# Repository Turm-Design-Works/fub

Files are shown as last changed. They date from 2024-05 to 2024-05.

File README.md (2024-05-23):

# fub.*~
**Pocket MIDI interface for Foot Switch &amp; Expression Pedal**  
  
Type-C :  
> to HOST

6.35 jack × 4 :  
> LEFT 2 jacks | Foot Switch jack. (Dual Foot Switch is available.)  
> RIGHT 2 jacks | Expression Pedal jack.

DIN 5pin × 1 :  
> MIDI OUT. This outputs MIDI datas of Foot SWs&Pedals and Note,CC,etc from Host.  

It is using ATSAND21G18A microcom chip as core.  



# LICENSES  
**MIT** ( [view LICENSE](https://github.com/Turm-Design-Works/fub/blob/main/LICENSE) )  
2024 Turm Design Works LLC.

# How to install firmware  
It needs to install "microchip(Atmel) studio", and prepare SAM/ARM writer (e. Atmel ICE, PICkit, j-link) with 5 debug wires.  
  
1. Solder all parts.
2. Connect fub.*~ & SAM/ARM writer to your PC.
3. Connect writer to fub.*~ PCB empty holes is marked "R V G C D" by using debug wire.  
> R: RESET, V: VTG 3.3V, G: GND, C: SWCLK, D: SWDIO  
> Please follow the connection of writer outputs you use.  
>   
4. Open microchip studio application.
> Move to "Tools" -> "Device Programming".  
>   
5. Apply writer and read chip.
> 1: Select writer you use, 2: Select Device "ATSAMD21G18A", 3: Select Interface "SWD",  
> 4: Click "Apply", 5: Click "Read"  
>   
6. Move to memories tab, program .hex firmware.
> 1: Click "Erase now", 2: Select fub_boot_v.v.v.v.hex firmware, 3: Click "Program"
>   
7. Disconnect fub.*~ and ARM writer from PC, and disconnect debug wire. Done.

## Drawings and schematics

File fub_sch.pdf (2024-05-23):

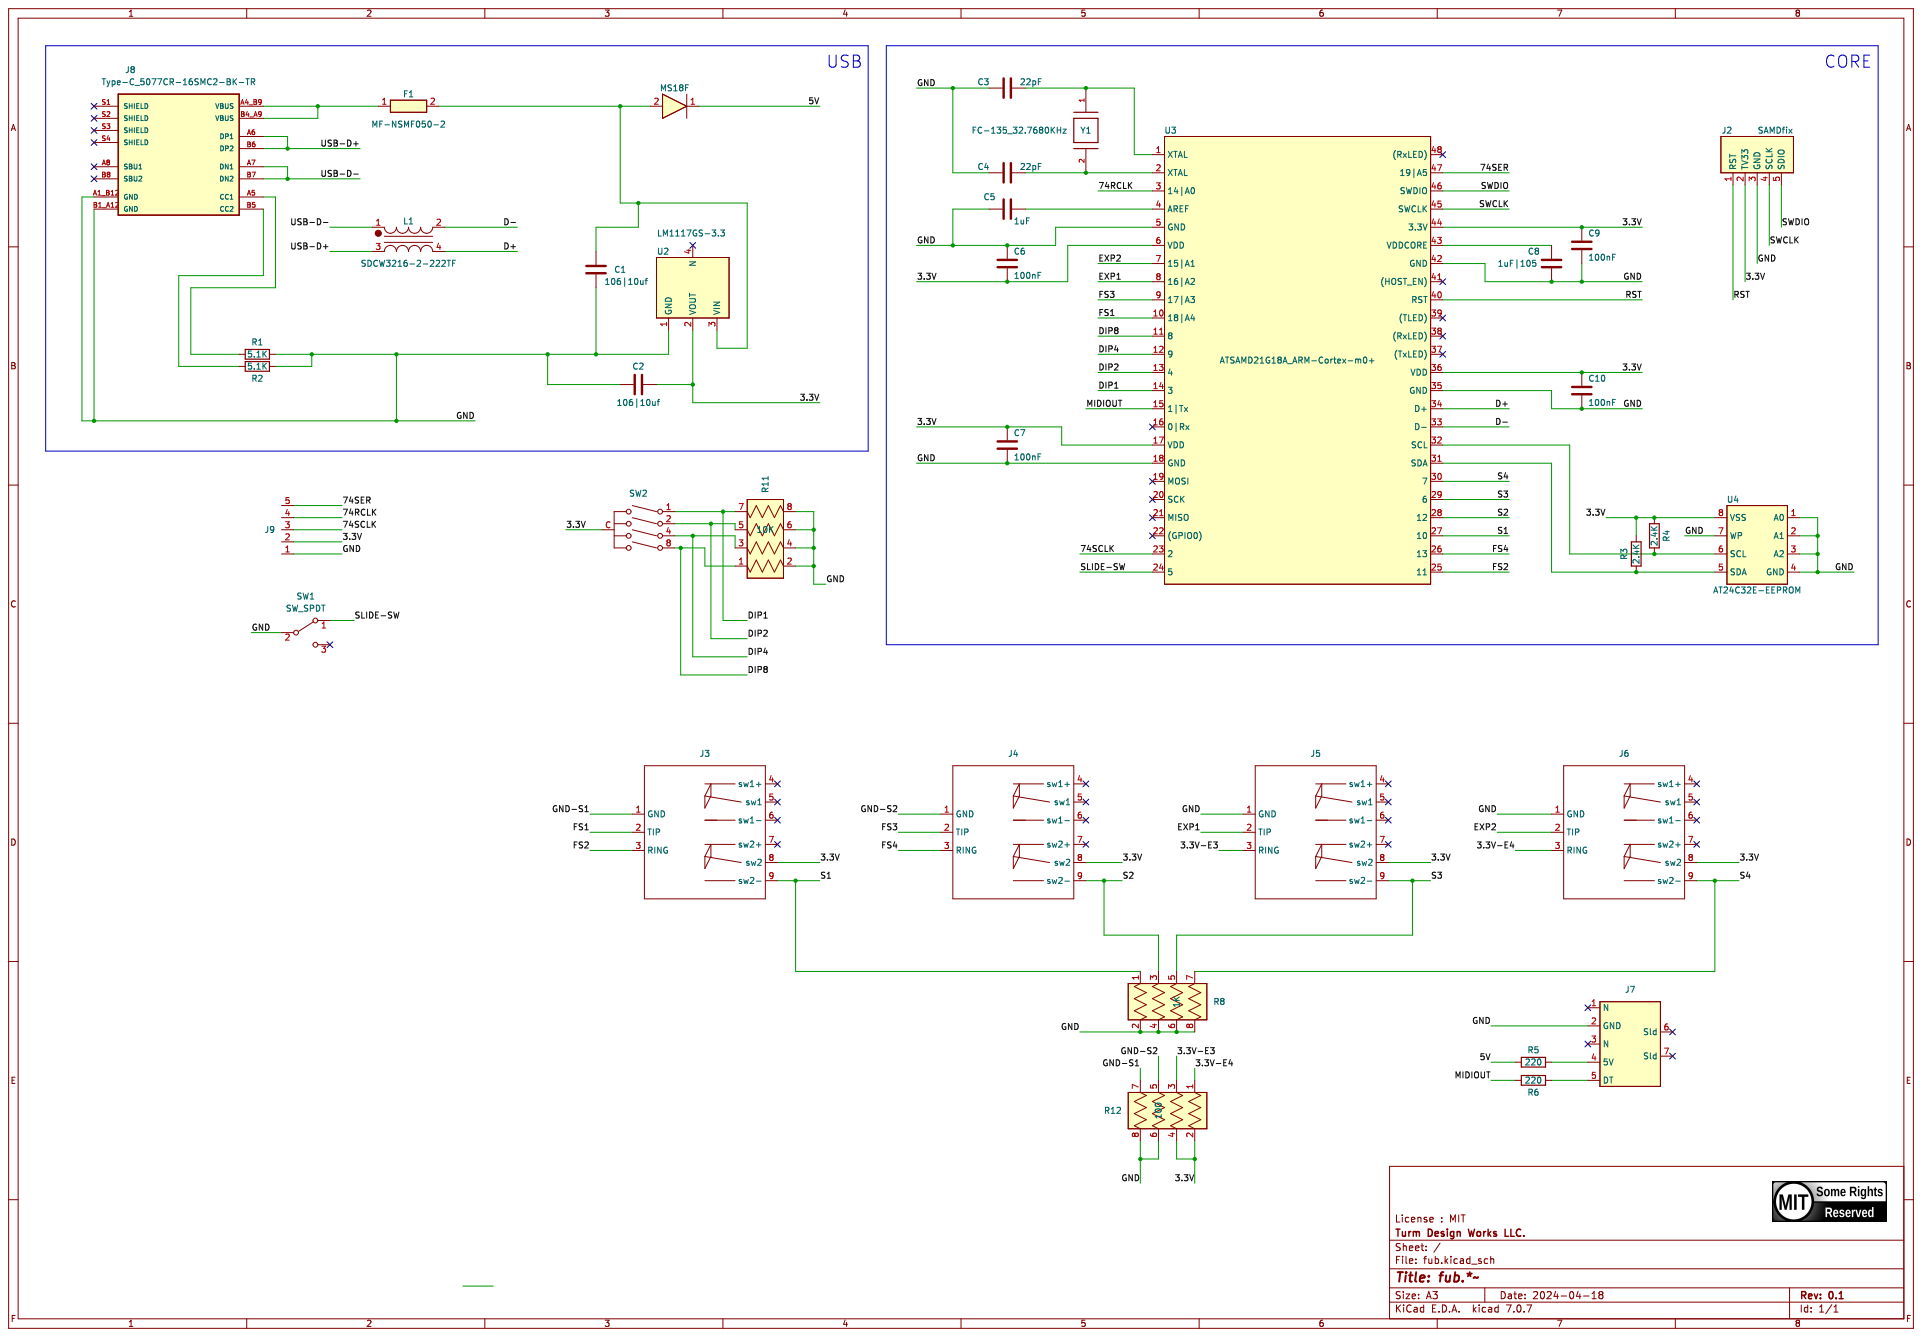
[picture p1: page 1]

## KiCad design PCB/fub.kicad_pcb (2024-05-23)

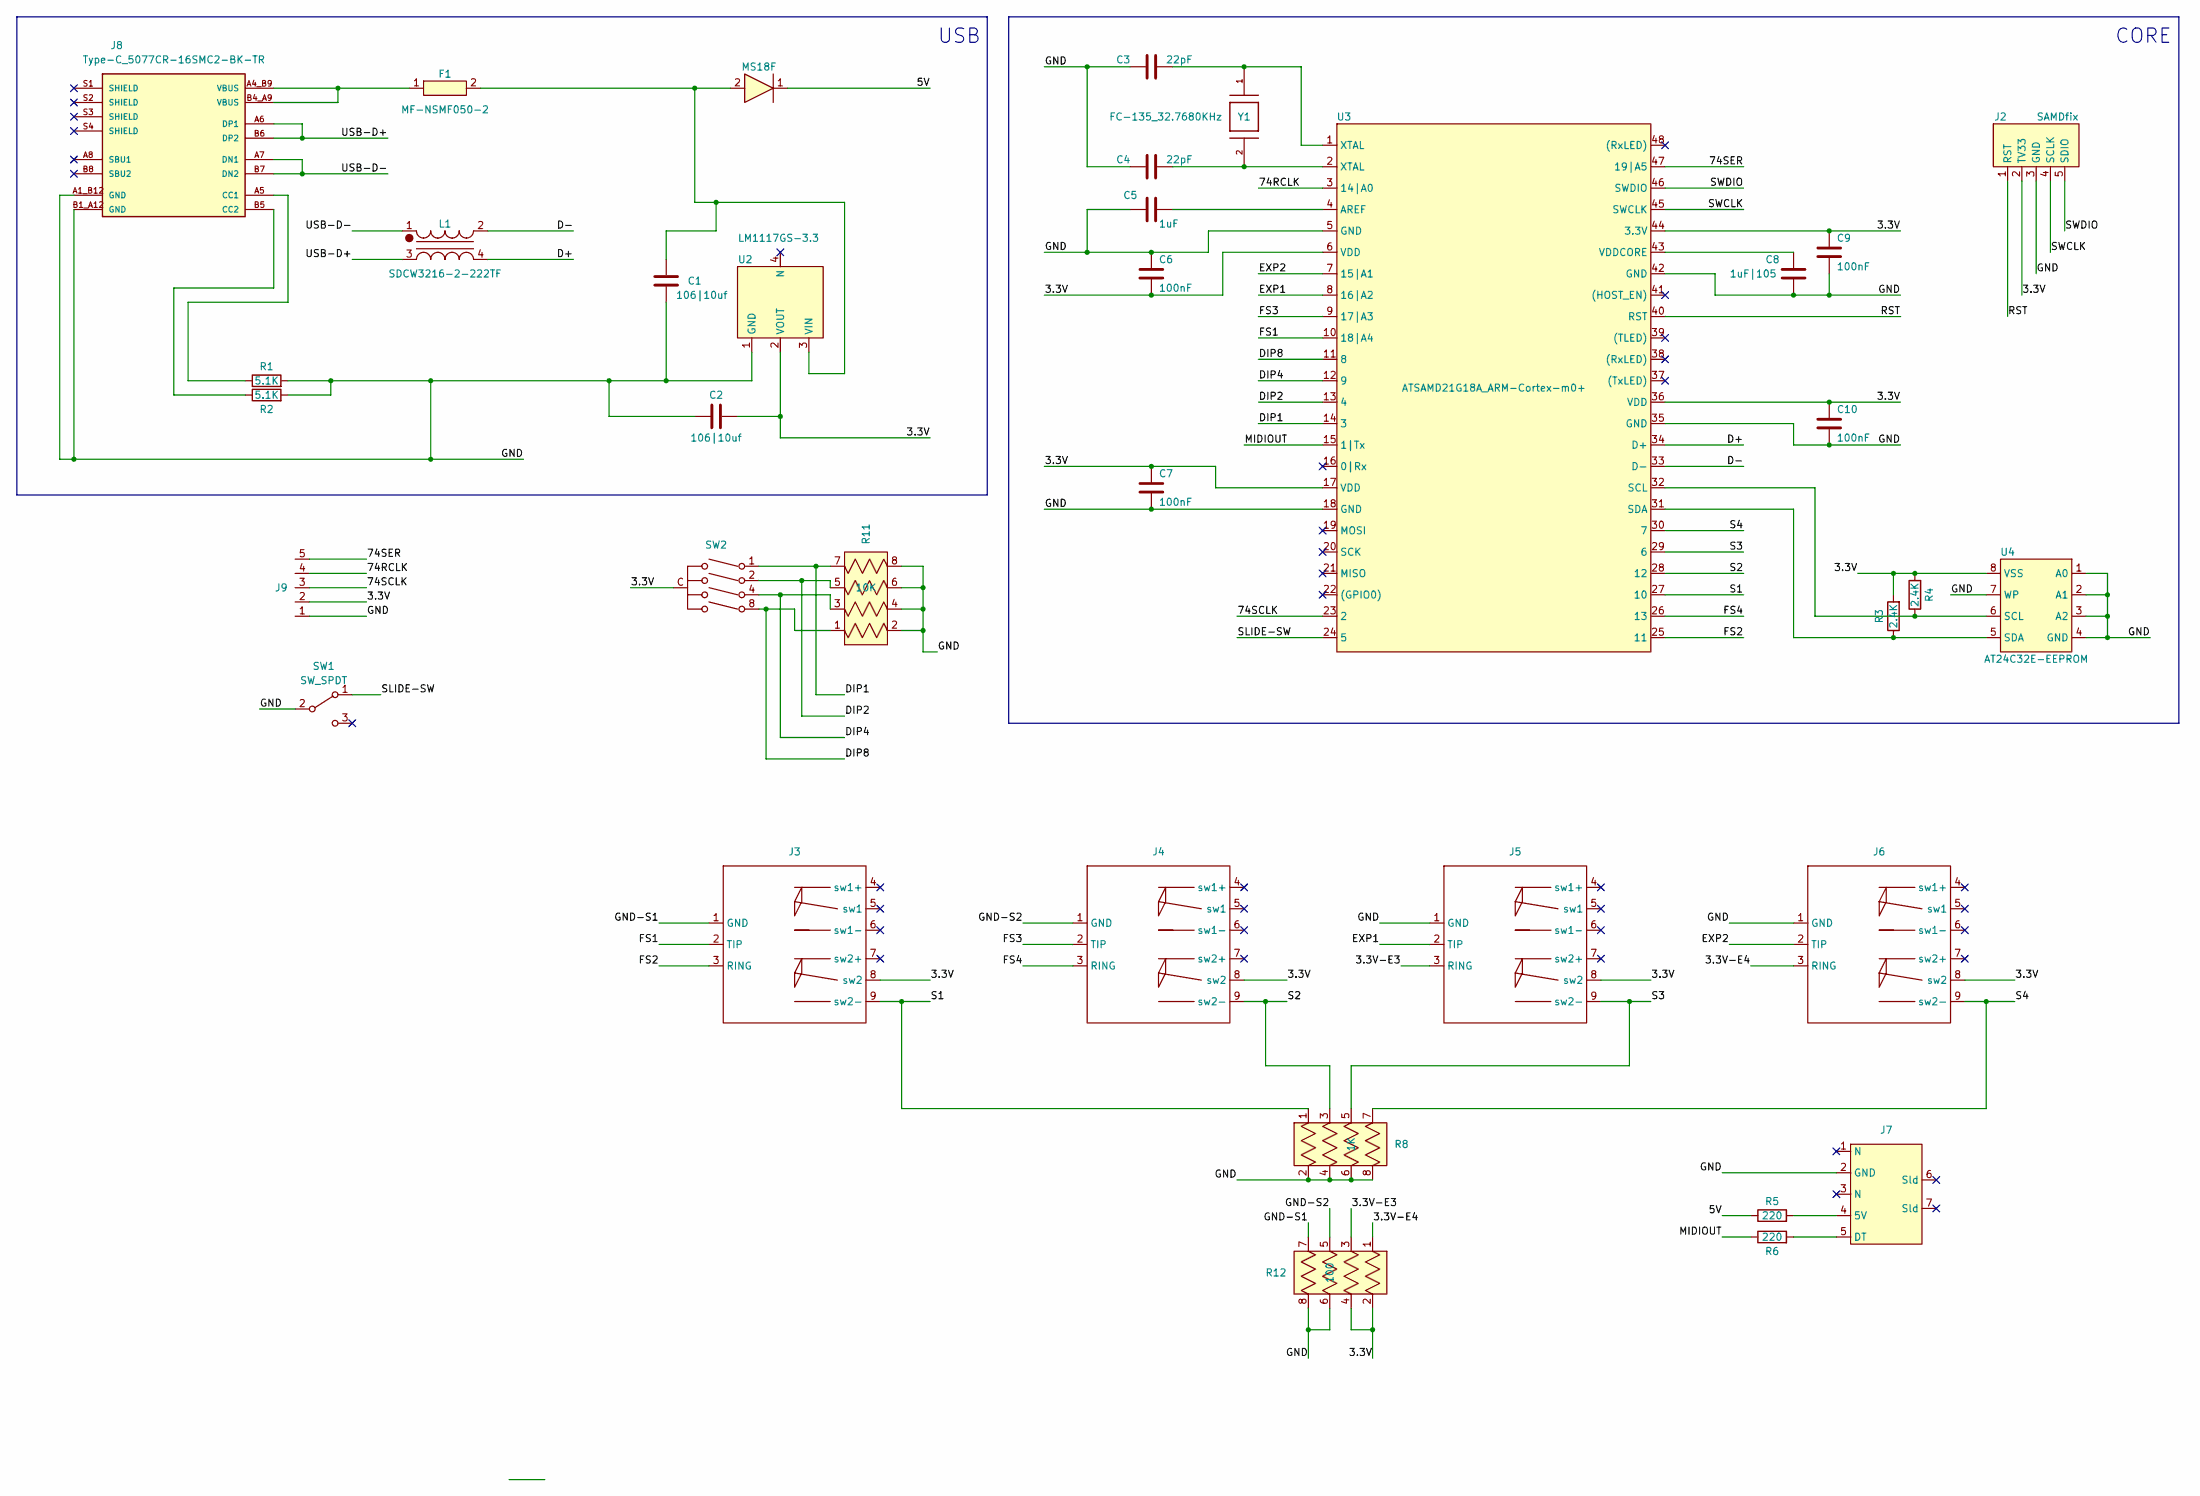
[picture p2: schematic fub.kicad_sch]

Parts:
C1, C2: 106|10uf; C_0603_1608Metric
C3, C4: 22pF; C_0603_1608Metric
C5: 1uF; C_0603_1608Metric
C6, C7, C9, C10: 100nF; C_0603_1608Metric
C8: 1uF|105; C_0603_1608Metric
F1: MF-NSMF050-2; MF-NSMF
J2: SAMDfix; 5tht
J3, J4, J5, J6: MJ-188LPD-8C
J7: KDJ03-5_MIDI
J8: Type-C_5077CR-16SMC2-BK-TR; NELTRON_5077CR-16SMC2-BK-TR
J9: 5ZH
L1: SDCW3216-2-222TF
R1, R2: 5.1K; R_0603_1608Metric
R3, R4: 2.4K; R_0603_1608Metric
R5, R6: 220; R_0603_1608Metric
R8: 1K; BCN164AB221J7
R11: 10K; MNR04M0ABJ103_register-arrray-small
R12: 100; BCN164AB221J7
SW1: SW_SPDT; SS-12D01G3_SLIDE-SW
SW2: FR01_dip-rotary16
U1: MS18F; MS18F_BARRIER
U2: LM1117GS-3.3; SOT-223
U3: ATSAMD21G18A_ARM-Cortex-m0+; QFP50P900X900X120-48N
U4: AT24C32E-EEPROM; SOIC-8_3.9x4.9mm_P1.27mm
Y1: FC-135_32.7680KHz; XTAL_FC-135_32.7680KA-A0

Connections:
/3.3V: C2.2, C6.1, C7.2, C9.2, C10.2, J2.2 (TV33), J3.8 (sw2), J4.8 (sw2), J5.8 (sw2), J6.8 (sw2), J9.2, R3.2, R4.2, R12.2, R12.4, SW2.C, U2.2 (VOUT), U3.6 (VDD), U3.17 (VDD), U3.36 (VDD), U3.44 (3.3V), U4.8 (VSS)
/3.3V-E3: J5.3 (RING), R12.3
/3.3V-E4: J6.3 (RING), R12.1
/5V: R5.1, U1.1
/74RCLK: J9.4, U3.3 (14|A0)
/74SCLK: J9.3, U3.23 (2)
/74SER: J9.5, U3.47 (19|A5)
/D+: L1.4, U3.34 (D+)
/D-: L1.2, U3.33 (D-)
/DIP1: R11.7, SW2.1, U3.14 (3)
/DIP2: R11.5, SW2.2, U3.13 (4)
/DIP4: R11.3, SW2.4, U3.12 (9)
/DIP8: R11.1, SW2.8, U3.11 (8)
/EXP1: J5.2 (TIP), U3.8 (16|A2)
/EXP2: J6.2 (TIP), U3.7 (15|A1)
/FS1: J3.2 (TIP), U3.10 (18|A4)
/FS2: J3.3 (RING), U3.25 (11)
/FS3: J4.2 (TIP), U3.9 (17|A3)
/FS4: J4.3 (RING), U3.26 (13)
/GND: C1.2, C2.1, C3.2, C4.2, C5.2, C6.2, C7.1, C8.1, C9.1, C10.1, J2.3 (GND), J5.1 (GND), J6.1 (GND), J7.2 (GND), J8.A1_B12 (GND), J8.B1_A12 (GND), J9.1, R1.2, R2.2, R8.2, R8.4, R8.6, R8.8, R11.2, R11.4, R11.6, R11.8, R12.6, R12.8, SW1.2 (B), U2.1 (GND), U3.5 (GND), U3.18 (GND), U3.35 (GND), U3.42 (GND), U4.1 (A0), U4.2 (A1), U4.3 (A2), U4.4 (GND), U4.7 (WP)
/GND-S1: J3.1 (GND), R12.7
/GND-S2: J4.1 (GND), R12.5
/MIDIOUT: R6.1, U3.15 (1|Tx)
/RST: J2.1 (RST), U3.40 (RST)
/S1: J3.9 (sw2-), R8.1, U3.27 (10)
/S2: J4.9 (sw2-), R8.3, U3.28 (12)
/S3: J5.9 (sw2-), R8.5, U3.29 (6)
/S4: J6.9 (sw2-), R8.7, U3.30 (7)
/SLIDE-SW: SW1.1 (A), U3.24 (5)
/SWCLK: J2.4 (SCLK), U3.45 (SWCLK)
/SWDIO: J2.5 (SDIO), U3.46 (SWDIO)
/USB-D+: J8.A6 (DP1), J8.B6 (DP2), L1.3
/USB-D-: J8.A7 (DN1), J8.B7 (DN2), L1.1
unnamed: C3.1, U3.1 (XTAL), Y1.1
unnamed: C4.1, U3.2 (XTAL), Y1.2
unnamed: F1.1, J8.A4_B9 (VBUS), J8.B4_A9 (VBUS)
unnamed: J7.4 (5V), R5.2
unnamed: J7.5 (DT), R6.2
unnamed: J8.A5 (CC1), R1.1
unnamed: J8.B5 (CC2), R2.1
unnamed: C1.1, F1.2, U1.2, U2.3 (VIN)
unnamed: C5.1, U3.4 (AREF)
unnamed: R4.1, U3.32 (SCL), U4.6 (SCL)
unnamed: R3.1, U3.31 (SDA), U4.5 (SDA)
unnamed: C8.2, U3.43 (VDDCORE)

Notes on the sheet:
CORE
USB

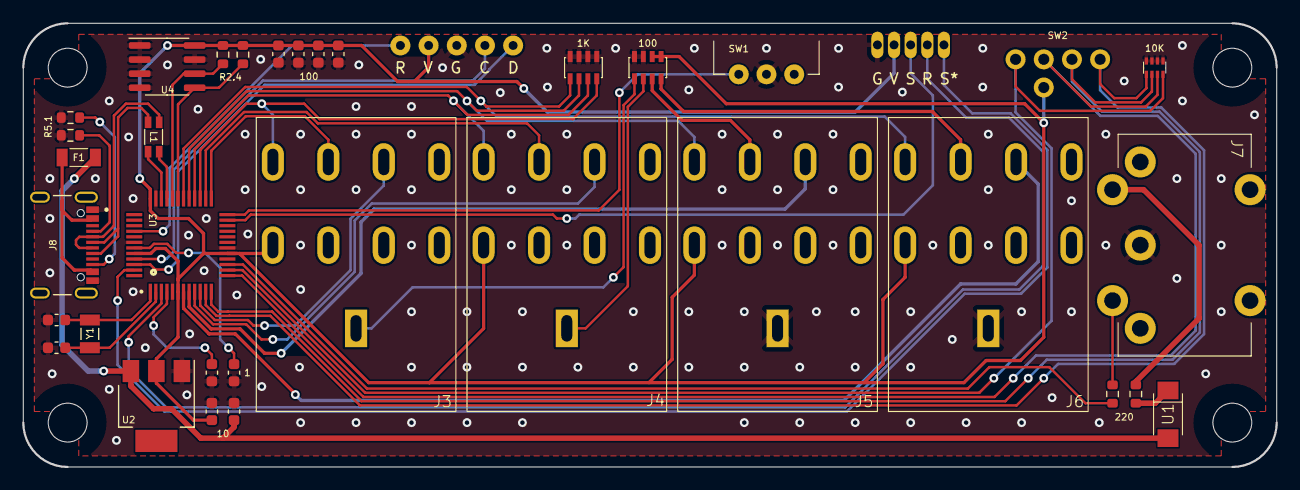
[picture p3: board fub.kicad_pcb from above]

Board: 2 copper layers, 113.0 x 40.0 mm, 36 parts (0 on the bottom side), 45 nets.

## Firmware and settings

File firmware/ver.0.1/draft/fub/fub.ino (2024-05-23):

/*
  SPDX-FileCopyrightText: 2024 Turm Design Works LLC. <info@turmdesignworks.com>
  SPDX-License-Identifier: MIT

  Seeed SAMD21 version 1.8.3 required.
*/

#include "MIDIUSB.h"
#include "Wire.h"

// average calc times
const byte AVGCT = 5;

// S Pins Switch
const int Pin_S[4] = {10, 12, 6, 7};

// V Pins Value (1-RING, 1-TIP, 2-RING, 2-TIP, 1-EXP, 2-EXP)
const int Pin_V[6] = {11, A4, 13, A3, A2, A1};

// Slide SW Pin
const int Pin_SL = 5;

// 7seg Pin
const int Pin_SER = A5;
const int Pin_SCLK = 2;
const int Pin_RCLK = A0;

// DIP Switch Pin
const int Pin_D[4] = {3, 4, 9, 8};

// DIP Switch Values
byte DIPV[4] = {0, 0, 0, 0};

// DIP Switch result
byte DIPNUM = 0;
byte DIPNUMp = 0;

// FS Random Value
byte RAND[4] = {0, 0, 0, 0};

/////////////////////////////////////////////// Function Mode
/////////////////////////////////////////////// FS : 0.Latch CC, 1.Moment CC, 2.Random CC, 3.PGM, 4.Note, 5.BANK++, 6.BANK--
/////////////////////////////////////////////// EXP: 0.CC, 1.CC (Reverse)
byte MODE[6] = {4, 4, 5, 6, 0, 0};

// BANK Value
byte BANK = 0;
byte BANKp = 255;

/////////////////////////////////////////////// FS+EXP MIDI Channel
byte MIDICH[6] = {0, 0, 0, 0, 0, 0};

/////////////////////////////////////////////// FS+EXP CCID
byte CCID[6] = {64, 65, 66, 67, 7, 11};

/////////////////////////////////////////////// EXP Curve
byte curve[2] = {1, 1};

/////////////////////////////////////////////// FS+EXP CC Minimum Value
byte MINV[6] = {0, 0, 0, 0, 0, 0};
/////////////////////////////////////////////// FS+EXP CC Maximum Value
byte MAXV[6] = {127, 127, 127, 127, 127, 127};

/////////////////////////////////////////////// FS CC Random Minimum Value
byte MINR[4] = {0, 0, 0, 0};
/////////////////////////////////////////////// FS CC Random Maximum Value
byte MAXR[4] = {127, 127, 127, 127};

/////////////////////////////////////////////// FS Program Change Value 0~127 outputs 1~128
byte PGMV[4] = {19, 20, 21, 22};

/////////////////////////////////////////////// FS Note Number
byte NOTE[4] = {48, 50, 52, 53};

/////////////////////////////////////////////// FS Velocity
byte VELO[4] = {64, 64, 64, 64};

/////////////////////////////////////////////// FS POLALITY TYPE
byte NCO[4] = {0, 0, 1, 1};

/////////////////////////////////////////////// EEPROM DATA to BANK
/////////////////////////////////////////////// 0~5:MODE, 6~11:MIDICH, 12~17:CCID, 18~19:Curve, 20~25:MINV, 26~31:MAXV,
/////////////////////////////////////////////// 32~35:MINR, 36~39:MAXR, 40~43:PGMV, 44~47:NOTE, 48~51:VELO, 52~55:NCO
byte EEPV[10][56] = { 
    { /*MODE*/ 1, 1, 6, 5, 0, 0, /*MIDICH*/ 0, 0, 0, 0, 0, 0, /*CCID*/ 64, 69, 0, 0, 7, 11, /*Curve*/ 1, 1, /*MINV*/ 0, 0, 0, 0, 0, 0, /*MAXV*/ 127, 127, 127, 127, 127, 127, /*MINR*/ 0, 0, 0, 0,  /*MAXR*/ 127, 127, 127, 127, /*PGMV*/ 0, 0, 0, 0, /*NOTE*/ 48, 50, 52, 53, /*VELO*/ 64, 64, 64, 64, /*NCO*/ 0, 0, 0, 0 },
    { /*MODE*/ 0, 0, 6, 5, 0, 0, /*MIDICH*/ 0, 0, 0, 0, 0, 0, /*CCID*/ 82, 83, 0, 0, 7, 11, /*Curve*/ 1, 1, /*MINV*/ 0, 0, 0, 0, 0, 0, /*MAXV*/ 127, 127, 127, 127, 127, 127, /*MINR*/ 0, 0, 0, 0,  /*MAXR*/ 127, 127, 127, 127, /*PGMV*/ 0, 0, 0, 0, /*NOTE*/ 48, 50, 52, 53, /*VELO*/ 64, 64, 64, 64, /*NCO*/ 0, 0, 0, 0 },
    { /*MODE*/ 2, 2, 6, 5, 0, 0, /*MIDICH*/ 0, 0, 0, 0, 0, 0, /*CCID*/ 1, 2, 0, 0, 7, 11, /*Curve*/ 1, 1, /*MINV*/ 0, 0, 0, 0, 0, 0, /*MAXV*/ 127, 127, 127, 127, 127, 127, /*MINR*/ 0, 0, 0, 0,  /*MAXR*/ 127, 127, 127, 127, /*PGMV*/ 0, 0, 0, 0, /*NOTE*/ 48, 50, 52, 53, /*VELO*/ 64, 64, 64, 64, /*NCO*/ 0, 0, 0, 0 },
    { /*MODE*/ 3, 3, 6, 5, 0, 0, /*MIDICH*/ 0, 0, 0, 0, 0, 0, /*CCID*/ 0, 0, 0, 0, 7, 11, /*Curve*/ 1, 1, /*MINV*/ 0, 0, 0, 0, 0, 0, /*MAXV*/ 127, 127, 127, 127, 127, 127, /*MINR*/ 0, 0, 0, 0,  /*MAXR*/ 127, 127, 127, 127, /*PGMV*/ 1, 2, 0, 0, /*NOTE*/ 48, 50, 52, 53, /*VELO*/ 64, 64, 64, 64, /*NCO*/ 0, 0, 0, 0 },
    { /*MODE*/ 4, 4, 6, 5, 0, 0, /*MIDICH*/ 0, 0, 0, 0, 0, 0, /*CCID*/ 0, 0, 0, 0, 7, 11, /*Curve*/ 1, 1, /*MINV*/ 0, 0, 0, 0, 0, 0, /*MAXV*/ 127, 127, 127, 127, 127, 127, /*MINR*/ 0, 0, 0, 0, /*MAXR*/ 127, 127, 127, 127, /*PGMV*/ 0, 0, 0, 0, /*NOTE*/ 48, 50, 52, 53, /*VELO*/ 64, 64, 64, 64, /*NCO*/ 0, 0, 0, 0 },
    { /*MODE*/ 1, 1, 6, 5, 1, 1, /*MIDICH*/ 0, 0, 0, 0, 0, 0, /*CCID*/ 64, 69, 0, 0, 7, 11, /*Curve*/ 1, 1, /*MINV*/ 0, 0, 0, 0, 0, 0, /*MAXV*/ 127, 127, 127, 127, 127, 127, /*MINR*/ 0, 0, 0, 0, /*MAXR*/ 127, 127, 127, 127, /*PGMV*/ 0, 0, 0, 0, /*NOTE*/ 48, 50, 52, 53, /*VELO*/ 64, 64, 64, 64, /*NCO*/ 0, 0, 0, 0 },
    { /*MODE*/ 0, 0, 6, 5, 1, 1, /*MIDICH*/ 0, 0, 0, 0, 0, 0, /*CCID*/ 82, 83, 0, 0, 7, 11, /*Curve*/ 1, 1, /*MINV*/ 0, 0, 0, 0, 0, 0, /*MAXV*/ 127, 127, 127, 127, 127, 127, /*MINR*/ 0, 0, 0, 0, /*MAXR*/ 127, 127, 127, 127, /*PGMV*/ 0, 0, 0, 0, /*NOTE*/ 48, 50, 52, 53, /*VELO*/ 64, 64, 64, 64, /*NCO*/ 0, 0, 0, 0 },
    { /*MODE*/ 2, 2, 6, 5, 1, 1, /*MIDICH*/ 0, 0, 0, 0, 0, 0, /*CCID*/ 1, 2, 0, 0, 7, 11, /*Curve*/ 1, 1, /*MINV*/ 0, 0, 0, 0, 0, 0, /*MAXV*/ 127, 127, 127, 127, 127, 127, /*MINR*/ 0, 0, 0, 0, /*MAXR*/ 127, 127, 127, 127, /*PGMV*/ 0, 0, 0, 0, /*NOTE*/ 48, 50, 52, 53, /*VELO*/ 64, 64, 64, 64, /*NCO*/ 0, 0, 0, 0 },
    { /*MODE*/ 3, 3, 6, 5, 1, 1, /*MIDICH*/ 0, 0, 0, 0, 0, 0, /*CCID*/ 0, 0, 0, 0, 7, 11, /*Curve*/ 1, 1, /*MINV*/ 0, 0, 0, 0, 0, 0, /*MAXV*/ 127, 127, 127, 127, 127, 127, /*MINR*/ 0, 0, 0, 0, /*MAXR*/ 127, 127, 127, 127, /*PGMV*/ 1, 2, 0, 0, /*NOTE*/ 48, 50, 52, 53, /*VELO*/ 64, 64, 64, 64, /*NCO*/ 0, 0, 0, 0 },
    { /*MODE*/ 4, 4, 6, 5, 1, 1, /*MIDICH*/ 0, 0, 0, 0, 0, 0, /*CCID*/ 0, 0, 0, 0, 7, 11, /*Curve*/ 1, 1, /*MINV*/ 0, 0, 0, 0, 0, 0, /*MAXV*/ 127, 127, 127, 127, 127, 127, /*MINR*/ 0, 0, 0, 0, /*MAXR*/ 127, 127, 127, 127, /*PGMV*/ 0, 0, 0, 0, /*NOTE*/ 48, 50, 52, 53, /*VELO*/ 64, 64, 64, 64, /*NCO*/ 0, 0, 0, 0 },
  };

// Jack Switch Values
byte ON[4] = {0, 0, 0, 0};
byte ONp[4] = {0, 0, 0, 0};

//EXP FLAG
byte outFLAG[2] = {0, 0};
byte outFLAGp[2] = {0, 0};

// Read Value is "times of for()"
int VAL[6] = {0, 0, 0, 0, 0, 0};
int VALp[6] = {0, 0, 0, 0, 0, 0};

// Foot Switch State for output pipe*~ delay
byte FS_State[4] = {0, 0, 0, 0};
byte FSp_State[4] = {0, 0, 0, 0};

// FootSwitch result Value
byte FootSwitch[4] = {0, 0, 0, 0};

// EXP Average of Vals
int AVV[2] = {0, 0};
int AVVp[2] = {0, 0};

//detect maxexpvalue
int MAXSTOMP[2] = {1011, 1011};

//detect minexpvalue
int MINSTOMP[2] = {24, 24};

//EXP sorted
byte EXP[2] = {0, 0};
byte EXPp[2] = {0, 0};

//EXP result
int EXPCCV[2] = {0, 0};
int EXPCCVp[2] = {0, 0};

//for output waiting time
unsigned long CTM[4] = {0, 0, 0, 0};

//for calc waiting time
unsigned long VTM[6] = {0, 0, 0, 0, 0, 0};

//SIDE-SW Value
byte SLSW = 0;
byte SLSWp = 0;
byte LCDR = 0;


//MIDI for USB

void controlChange(byte channel, byte control, byte value) {
  midiEventPacket_t event = {0x0B, 0xB0 | channel, control, value};
  MidiUSB.sendMIDI(event);
}

void programChange(byte channel, byte program) {
  midiEventPacket_t pc = {0x0C, 0xC0 | channel, program, 0};
  MidiUSB.sendMIDI(pc);
}

void noteOn(byte channel, byte pitch, byte velocity) {
  midiEventPacket_t noteOn = {0x09, 0x90 | channel, pitch, velocity};
  MidiUSB.sendMIDI(noteOn);
}

void noteOff(byte channel, byte pitch, byte velocity) {
  midiEventPacket_t noteOff = {0x08, 0x80 | channel, pitch, velocity};
  MidiUSB.sendMIDI(noteOff);
}

void SysExStart(byte ROW, byte COL) {
  midiEventPacket_t event = {0x04, 0xF0, ROW, COL};
  MidiUSB.sendMIDI(event);
}

void SysExEND(byte sVAL ) {
  midiEventPacket_t event = {0x06, sVAL,0xF7, 0x00};
  MidiUSB.sendMIDI(event);
}



//MIDI for DIN5

void D_controlChange(byte channel, byte control, byte value) {
  Serial1.write( 0xB0 | channel );
  Serial1.write( control );
  Serial1.write( value );
  Serial1.flush();
}

void D_programChange(byte channel, byte value) {
  Serial1.write( 0xC0 | channel );
  Serial1.write( value );
  Serial1.flush();
}

void D_noteOn(byte channel, byte pitch, byte velocity) {
  Serial1.write( 0x90 | channel );
  Serial1.write( pitch );
  Serial1.write( velocity );
  Serial1.flush();
}

void D_noteOff(byte channel, byte pitch, byte velocity) {
  Serial1.write( 0x80 | channel );
  Serial1.write( pitch );
  Serial1.write( velocity );
  Serial1.flush();
}



//Sync

uint8_t Sstart[4] = {0x0F, 0xFA, 0, 0};

uint8_t Sstop[4] = {0x0F, 0xFC, 0, 0};

uint8_t Sclock[4] = {0x0F, 0xF8, 0, 0};






//EEPROM

int Wadd;
byte waitEEP;

byte ROWid;
byte COLid;

void WriteEEP(int d_address, unsigned int rom_address, byte s_data){
  Wire.beginTransmission(d_address);
  Wire.write((int)(rom_address >> 8));
  Wire.write((int)(rom_address & 0xFF));
  Wire.write(s_data);
  Wire.endTransmission();
}

byte ReadEEP(int d_address, unsigned int rom_address){
  Wire.beginTransmission(d_address);
  Wire.write((int)(rom_address >> 8));
  Wire.write((int)(rom_address & 0xFF));
  Wire.endTransmission();

  Wire.requestFrom(d_address,1);
  if(Wire.available()){}
  return Wire.read();
}  





//7 SEGMENT Patterns OSL10561-LB

byte SEGP[11] = {
    B10111110, //0       0
    B00101000, //1       1
    B10011101, //2       2
    B00111101, //3       3
    B00101011, //4       4
    B00110111, //5       5
    B10110111, //6       6
    B00101110, //7       7
    B10111111, //8       8
    B00111111, //9       9
    B00000000, //Null    10
};

byte SEGPr[11] = {
    B10111110, //0       0
    B10000010, //1       1
    B10011101, //2       2
    B10010111, //3       3
    B10100011, //4       4
    B00110111, //5       5
    B00111111, //6       6
    B10110010, //7       7
    B10111111, //8       8
    B10110111, //9       9
    B00000000, //Null    10
};





void setup() {

  
  /////////////////////////////////////////////////////////////////// PinMode SetUp
  
  for (byte i=0; i <= 3; i++){
    pinMode( Pin_S[i], INPUT );
    pinMode( Pin_D[i], INPUT );
  }

  pinMode( Pin_V[0], INPUT_PULLUP );
  pinMode( Pin_V[1], INPUT_PULLUP );
  pinMode( Pin_V[2], INPUT_PULLUP );
  pinMode( Pin_V[3], INPUT_PULLUP );

  pinMode( Pin_SL, INPUT_PULLUP );

  pinMode( Pin_SER, OUTPUT );
  pinMode( Pin_SCLK, OUTPUT );
  pinMode( Pin_RCLK, OUTPUT );

  delay(100);

  digitalWrite( Pin_RCLK, LOW );
  shiftOut( Pin_SER, Pin_SCLK, LSBFIRST, SEGP[0] );
  digitalWrite( Pin_RCLK, HIGH );



  /////////////////////////////////////////////////////////////////// LCD BLACKOUT
  
  digitalWrite( Pin_RCLK, LOW );
  shiftOut( Pin_SER, Pin_SCLK, LSBFIRST, SEGP[10] );
  digitalWrite( Pin_RCLK, HIGH );


  
  /////////////////////////////////////////////////////////////////// Transmission Begin

  Serial1.begin(31250);  
  SerialUSB.begin(115200);
  Wire.begin();
  //WriteEEP(0x50, 0, 88);
  delay (1000);



  /////////////////////////////////////////////////////////////////// Read EEPROM

  for ( byte i=0; i <= 55; i++ ){
    if ( int r=0; ReadEEP(0x50, i) <= 127 ){ EEPV[r][i] = ReadEEP(0x50, i); delay(5); } else { delay(5); }
    if ( int r=1, p=56; ReadEEP(0x50, i+p) <= 127 ){ EEPV[r][i] = ReadEEP(0x50, i+p); delay(5); } else { delay(5); }
    if ( int r=2, p=112; ReadEEP(0x50, i+p) <= 127 ){ EEPV[r][i] = ReadEEP(0x50, i+p); delay(5); } else { delay(5); }
    if ( int r=3, p=168; ReadEEP(0x50, i+p) <= 127 ){ EEPV[r][i] = ReadEEP(0x50, i+p); delay(5); } else { delay(5); }
    if ( int r=4, p=224; ReadEEP(0x50, i+p) <= 127 ){ EEPV[r][i] = ReadEEP(0x50, i+p); delay(5); } else { delay(5); }
    if ( int r=5, p=280; ReadEEP(0x50, i+p) <= 127 ){ EEPV[r][i] = ReadEEP(0x50, i+p); delay(5); } else { delay(5); }
    if ( int r=6, p=336; ReadEEP(0x50, i+p) <= 127 ){ EEPV[r][i] = ReadEEP(0x50, i+p); delay(5); } else { delay(5); }
    if ( int r=7, p=392; ReadEEP(0x50, i+p) <= 127 ){ EEPV[r][i] = ReadEEP(0x50, i+p); delay(5); } else { delay(5); }
    if ( int r=8, p=448; ReadEEP(0x50, i+p) <= 127 ){ EEPV[r][i] = ReadEEP(0x50, i+p); delay(5); } else { delay(5); }
    if ( int r=9, p=504; ReadEEP(0x50, i+p) <= 127 ){ EEPV[r][i] = ReadEEP(0x50, i+p); delay(5); } else { delay(5); }
    
    if ( i>=0 && i<=7 ) { digitalWrite( Pin_RCLK, LOW ); shiftOut( Pin_SER, Pin_SCLK, LSBFIRST, B00000001 ); digitalWrite( Pin_RCLK, HIGH ); }
    if ( i>=8 && i<=15 ) { digitalWrite( Pin_RCLK, LOW ); shiftOut( Pin_SER, Pin_SCLK, LSBFIRST, B00000010 ); digitalWrite( Pin_RCLK, HIGH ); }
    if ( i>=16 && i<=23 ) { digitalWrite( Pin_RCLK, LOW ); shiftOut( Pin_SER, Pin_SCLK, LSBFIRST, B00000100 ); digitalWrite( Pin_RCLK, HIGH ); }
    if ( i>=24 && i<=31 ) { digitalWrite( Pin_RCLK, LOW ); shiftOut( Pin_SER, Pin_SCLK, LSBFIRST, B00001000 ); digitalWrite( Pin_RCLK, HIGH ); }
    if ( i>=32 && i<=39 ) { digitalWrite( Pin_RCLK, LOW ); shiftOut( Pin_SER, Pin_SCLK, LSBFIRST, B00100000 ); digitalWrite( Pin_RCLK, HIGH ); }
    if ( i>=40 && i<=47 ) { digitalWrite( Pin_RCLK, LOW ); shiftOut( Pin_SER, Pin_SCLK, LSBFIRST, B00010000 ); digitalWrite( Pin_RCLK, HIGH ); }
    if ( i>=48 && i<=55 ) { digitalWrite( Pin_RCLK, LOW ); shiftOut( Pin_SER, Pin_SCLK, LSBFIRST, B10000000 ); digitalWrite( Pin_RCLK, HIGH ); }
    
  }
  

}


void loop() {


/////////////////////////////////////////////////////////////////////////////////////////////// MIDI Rx

  midiEventPacket_t rx;
  do {
    rx = MidiUSB.read();
    if ( rx.header != 0 ) {
      Serial.print("MIDI Rx: ");
      Serial.print(rx.header);
      Serial.print(", ");
      Serial.print(rx.byte1);
      Serial.print(", ");
      Serial.print(rx.byte2);
      Serial.print(", ");
      Serial.println(rx.byte3);

///////////////////////////////////////////////////////////// CC from HOST
      if ( rx.header == 11 ){
        D_controlChange( rx.byte1 - 176, rx.byte2, rx.byte3 ); 
      }
      
///////////////////////////////////////////////////////////// NOTE ON from HOST
      else if ( rx.header == 9 ){ 
        D_noteOn( rx.byte1 - 144, rx.byte2, rx.byte3 ); 
      }
      
///////////////////////////////////////////////////////////// NOTE OFF from HOST
      else if ( rx.header == 8 ){ 
        D_noteOn( rx.byte1 - 128, rx.byte2, rx.byte3 ); 
      }

///////////////////////////////////////////////////////////// Poly & After touch
      else if ( rx.header == 10 ){ 
        Serial1.write(rx.byte1);
        Serial1.write(rx.byte2);
        Serial1.write(rx.byte3);
      }

///////////////////////////////////////////////////////////// Channel After touch
      else if ( rx.header == 13 ){ 
        Serial1.write(rx.byte1);
        Serial1.write(rx.byte2);
      }
      
///////////////////////////////////////////////////////////// Pitch Bend
      else if ( rx.header == 14 ){ 
        Serial1.write(rx.byte1);
        Serial1.write(rx.byte2);
        Serial1.write(rx.byte3);
      }

///////////////////////////////////////////////////////////// 0 (future expanssion)
      else if ( rx.header == 0 ){ 
        
      }

///////////////////////////////////////////////////////////// 1 (Cable event. future expanssion)
      else if ( rx.header == 0 ){ 
        
      }

///////////////////////////////////////////////////////////// 2 Byte System Common MSG
      else if ( rx.header == 2 ){ 
        Serial1.write(rx.byte1);
        Serial1.write(rx.byte2);
      }

///////////////////////////////////////////////////////////// 3 Byte System Common MSG
      else if ( rx.header == 3 ){ 
        Serial1.write(rx.byte1);
        Serial1.write(rx.byte2);
        Serial1.write(rx.byte3);
      }
      
///////////////////////////////////////////////////////////// Single Byte Clock
      else if ( rx.header == 15 ){ 
        Serial1.write(rx.byte1);
      }
      
///////////////////////////////////////////////////////////// Program Change from HOST
      else if ( rx.header == 12 ){
        D_programChange( rx.byte1 - 192, rx.byte2 ); 
                                                           // PGM to BANNK (CH.16)
        if ( rx.byte1 == 207 ){
          BANK = constrain( rx.byte2, 0, 9);
        }
      }
      
///////////////////////////////////////////////////////////// System Exclusive from HOST
      else if ( rx.header == 4 ){
        waitEEP = 0;
        Serial1.write(rx.byte1);
        Serial1.write(rx.byte2);
        Serial1.write(rx.byte3);

        if ( rx.byte2 >= 100 && rx.byte2 <= 110 ){
          ROWid = rx.byte2;
          COLid = rx.byte3;
          Wadd = rx.byte3 + ( 55 * (rx.byte2 - 100) + (rx.byte2 - 100) );
          //Serial.print("Address: ");
          //Serial.println(Wadd);
          waitEEP = 1;
        }
      }

      else if ( rx.header == 5 ){ 
        Serial1.write(rx.byte1);
        Serial1.write(rx.byte2);
        Serial1.write(rx.byte3);
      }

      else if ( rx.header == 6 ){ 
        Serial1.write(rx.byte1);
        Serial1.write(rx.byte2);
        Serial1.write(rx.byte3);

        if ( waitEEP == 1 ){
          WriteEEP( 0x50, Wadd, rx.byte1 );
          delay(250);
          SysExStart( ROWid, COLid );
          SysExEND( 1 );
          MidiUSB.flush();
        }
      }

      else if ( rx.header == 7 ){ 
        Serial1.write(rx.byte1);
        Serial1.write(rx.byte2);
        Serial1.write(rx.byte3);
      }
        
    }
  } while (rx.header != 0);




/////////////////////////////////////////////////////////////////////////////////////////////// SLIDE SWITCH

  SLSW = digitalRead( Pin_SL );

  if ( SLSW != SLSWp ){
    LCDR = SLSW;
    SLSWp = SLSW;
  }

  

/////////////////////////////////////////////////////////////////////////////////////////////// JACK Connection

  for ( byte i=0; i <= 3; i++ ){ ON[i] = digitalRead(Pin_S[i]); }

  //SW1&2
  
  if ( byte i=0, ii=1; ON[i] != ONp[i] ){ 
    ONp[i] = ON[i]; 
//    noteOff(MIDICH[i], NOTE[i], VELO[i]);
//    noteOff(MIDICH[ii], NOTE[ii], VELO[ii]);
//    D_noteOff(MIDICH[i], NOTE[i], VELO[i]);
//    D_noteOff(MIDICH[ii], NOTE[ii], VELO[ii]);
    CTM[i] = millis() + 500; 
    delay(10); 
  }

  //SW3&4
  
  if ( byte i=1, ii=2, iii=3; ON[i] != ONp[i] ){ 
    ONp[i] = ON[i]; 
//    noteOff(MIDICH[ii], NOTE[ii], VELO[ii]);
//    noteOff(MIDICH[iii], NOTE[iii], VELO[iii]);
//    D_noteOff(MIDICH[ii], NOTE[ii], VELO[ii]);
//    D_noteOff(MIDICH[iii], NOTE[iii], VELO[iii]);
    CTM[i] = millis() + 500; 
    delay(10); 
  }

  //EXP1
  
  if ( byte i=2; ON[i] != ONp[i] ){ 
    ONp[i] = ON[i]; 
    CTM[i] = millis() + 500; 
    delay(10); 
  }

  //EXP2
  
  if ( byte i=3; ON[i] != ONp[i] ){ 
    ONp[i] = ON[i];
    CTM[i] = millis() + 500; 
    delay(10); 
  }


/////////////////////////////////////////////////////////////////////////////////////////////// DIP switch values
  
  for ( byte d=0, i=0; i <= 3; i++ ){
    DIPV[i] = digitalRead(Pin_D[i]);
    d = bitWrite(d, i, DIPV[i]);
    if (i==3) { DIPNUM = d; }
  }
  
  if ( DIPNUM != DIPNUMp ){
    BANK = DIPNUM;
    SerialUSB.print("DIP : ");
    SerialUSB.println(DIPNUM);
    DIPNUMp = DIPNUM;
  }


/////////////////////////////////////////////////////////////////////////////////////////////// EEP to BANK Param

  if ( BANK != BANKp ){
    for ( byte c=0; c <= 55; c++ ){
      //MODE
      if ( c == 0){ MODE[0] = EEPV[BANK][c]; }
      if ( c == 1){ MODE[1] = EEPV[BANK][c]; }
      if ( c == 2){ MODE[2] = EEPV[BANK][c]; }
      if ( c == 3){ MODE[3] = EEPV[BANK][c]; }
      if ( c == 4){ MODE[4] = EEPV[BANK][c]; }
      if ( c == 5){ MODE[5] = EEPV[BANK][c]; }
      //MIDICH
      if ( c == 6){ MIDICH[0] = EEPV[BANK][c]; }
      if ( c == 7){ MIDICH[1] = EEPV[BANK][c]; }
      if ( c == 8){ MIDICH[2] = EEPV[BANK][c]; }
      if ( c == 9){ MIDICH[3] = EEPV[BANK][c]; }
      if ( c == 10){ MIDICH[4] = EEPV[BANK][c]; }
      if ( c == 11){ MIDICH[5] = EEPV[BANK][c]; }
      //CCID
      if ( c == 12){ CCID[0] = EEPV[BANK][c]; }
      if ( c == 13){ CCID[1] = EEPV[BANK][c]; }
      if ( c == 14){ CCID[2] = EEPV[BANK][c]; }
      if ( c == 15){ CCID[3] = EEPV[BANK][c]; }
      if ( c == 16){ CCID[4] = EEPV[BANK][c]; }
      if ( c == 17){ CCID[5] = EEPV[BANK][c]; }
      //Curve
      if ( c == 18){ curve[0] = EEPV[BANK][c]; }
      if ( c == 19){ curve[1] = EEPV[BANK][c]; }
      //MINV
      if ( c == 20){ MINV[0] = EEPV[BANK][c]; }
      if ( c == 21){ MINV[1] = EEPV[BANK][c]; }
      if ( c == 22){ MINV[2] = EEPV[BANK][c]; }
      if ( c == 23){ MINV[3] = EEPV[BANK][c]; }
      if ( c == 24){ MINV[4] = EEPV[BANK][c]; }
      if ( c == 25){ MINV[5] = EEPV[BANK][c]; }
      //MAXV
      if ( c == 26){ MAXV[0] = EEPV[BANK][c]; }
      if ( c == 27){ MAXV[1] = EEPV[BANK][c]; }
      if ( c == 28){ MAXV[2] = EEPV[BANK][c]; }
      if ( c == 29){ MAXV[3] = EEPV[BANK][c]; }
      if ( c == 30){ MAXV[4] = EEPV[BANK][c]; }
      if ( c == 31){ MAXV[5] = EEPV[BANK][c]; }
      //MINR
      if ( c == 32){ MINR[0] = EEPV[BANK][c]; }
      if ( c == 33){ MINR[1] = EEPV[BANK][c]; }
      if ( c == 34){ MINR[2] = EEPV[BANK][c]; }
      if ( c == 35){ MINR[3] = EEPV[BANK][c]; }
      //MAXR
      if ( c == 36){ MAXR[0] = EEPV[BANK][c]; }
      if ( c == 37){ MAXR[1] = EEPV[BANK][c]; }
      if ( c == 38){ MAXR[2] = EEPV[BANK][c]; }
      if ( c == 39){ MAXR[3] = EEPV[BANK][c]; }
      //PGMV
      if ( c == 40){ PGMV[0] = EEPV[BANK][c]; }
      if ( c == 41){ PGMV[1] = EEPV[BANK][c]; }
      if ( c == 42){ PGMV[2] = EEPV[BANK][c]; }
      if ( c == 43){ PGMV[3] = EEPV[BANK][c]; }
      //NOTE
      if ( c == 44){ NOTE[0] = EEPV[BANK][c]; }
      if ( c == 45){ NOTE[1] = EEPV[BANK][c]; }
      if ( c == 46){ NOTE[2] = EEPV[BANK][c]; }
      if ( c == 47){ NOTE[3] = EEPV[BANK][c]; }
      //VELO
      if ( c == 48){ VELO[0] = EEPV[BANK][c]; }
      if ( c == 49){ VELO[1] = EEPV[BANK][c]; }
      if ( c == 50){ VELO[2] = EEPV[BANK][c]; }
      if ( c == 51){ VELO[3] = EEPV[BANK][c]; }
      //NCO
      if ( c == 52){ NCO[0] = EEPV[BANK][c]; }
      if ( c == 53){ NCO[1] = EEPV[BANK][c]; }
      if ( c == 54){ NCO[2] = EEPV[BANK][c]; }
      if ( c == 55){ NCO[3] = EEPV[BANK][c]; }
    }
    BANKp = BANK;
  }
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

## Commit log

2024-05-22 Create assemblypartslist
2024-05-23 Update assemblypartslist

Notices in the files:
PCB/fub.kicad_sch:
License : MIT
